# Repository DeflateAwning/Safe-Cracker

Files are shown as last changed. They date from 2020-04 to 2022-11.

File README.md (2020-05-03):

# Safe-Cracker
On a whim, I bought a Sentry Safe on Kijiji for cheap, without the combination. This system uses stepper motors to crack it.

## Acknowledgement
* This project is heavily based off the [sparkfunX project](https://github.com/sparkfunX/Safe_Cracker). Many of the 3D printed components are nearly a direct copy.
	* Licensing Information of the sparkfunX project: https://github.com/sparkfunX/Safe_Cracker/blob/master/LICENSE.md (MIT License)
* A 2040 Extrusion Angle Bracket was used from [Thingiverse.com](https://www.thingiverse.com/thing:3610780), user [jackw01](https://jackw01.github.io).
* A 2040 NEMA17 stepper motor mount was used from [Thingiverse.com](https://www.thingiverse.com/thing:3060289/files), user [grizzly3d](https://www.thingiverse.com/grizzly3d/about)
* Arduino [AccelStepper library](https://www.airspayce.com/mikem/arduino/AccelStepper/index.html).

## Disclaimer
* This project was built to crack open an **empty** safe that was sold to me for cheap, because the owner forgot the combination.
* As per the MIT License, I accept no responsibility for your use/adaptation of this project. Please act morally.

## 3D Printed Components
There are 3 printed components:

### Handle (SafeHandleGrip.stl)
* **Source:** Sparkfun Repository
* **Measured Dimensions:** 38mm x 118.5mm
* Dimensions match the file, using as is for now.

### Handle Pulley (NautilusPulley.stl)
* **Source:** Sparkfun Repository

### Dial (DialGrip.stl)
* **Source:** Personal OpenSCAD Design
* OD of Dial on Safe: \~79mm
* Has 12 notches around the outside
* Designed my own grip for it, supporting M5 bolts

### 2040 Aluminum Extrusion Mounts/Brackets
* Several 90-degree brackets for joining the extrusions together
	* **Source:** Thingiverse.com, see Acknowledgement
* Two motor mounts for mounting the NEMA17 steppers to the extrusions.
	* **Source:** Thingiverse.com, see Acknowledgement

## Electronics
### Devices Used
* The electronics of this system employ the [GRBL CNC Shield v3.00](https://blog.protoneer.co.nz/arduino-cnc-shield/) for the Arduino Uno (note that the associated GRBL firmware is not used). 
* 2x NEMA17 stepper motors, and one SPDT limit switch (used in NO mode)
* A 12v ATX PSU is used for power into the GRBL CNC Shield.
* A 1602 LCD screen may be used, but may not be. To be confirmed if communication will be primarily over Serial or not.
* The system will detect when unlocking was successful by one of two methods (TBD):
	1. ~Use a current sensor on the handle stepper motor (Y Axis). Easier mechnically, more difficult in electronics/firmware.~
	2. Use a limit switch SPDT switch to detect when the handle has moved. More difficult mechanically, easier in electronics/firmware. Far less creative.

### Connections to Arduino
* X Axis -> Dial
	* Dial Step Pin: D2
	* Dial Direction Pin: D5
	* Use 1/8 microstepping
	* Stepper Enable Pin: D8 (for all axes)
* Y Axis -> Handle
	* Handle Step Pin: D3
	* Handle Direction Pin: D6
	* No Microstepping (higher torque)
* X Limit Switch -> Handle Movement Detection
	* Input Pin: D9
	* Internal Pullup Resistor Used
	* Switch used in NO (normally open) mode, connected to GND (internal pullup resistor used)

## Hardware Design
* 2020 and 2040 aluminum extrusions will be used as the main frame, not because they are good, nor because they are cheap, but rather because it is May 2020 and we're all in quarantine, and it's all I have from dismantling an old CNC laser engraver.
* Various 3D printed components will be used. See breakdown of parts in 3D Printed Components section.
* Both stepper motors are **NEMA17** steppers:
	* One is used to turn the dial.
	* The other is used to pull on the handle to test when it is unlocked.

## Firmware Design
* The firmware will be losely based off the firmware provided by the sparkfunX project. It will run on an Arduino Uno, controlling the steppers through the GRBL shield (Arduino pins described in Electronics section).
* Uses the [AccelStepper library](https://www.airspayce.com/mikem/arduino/AccelStepper/index.html) to control the two stepper motors.

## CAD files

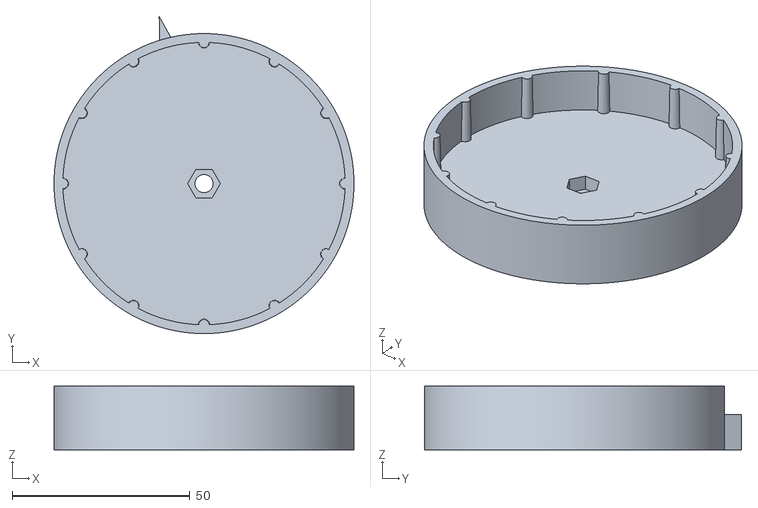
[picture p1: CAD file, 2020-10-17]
3D Models/DialGrip.stl
84.5 x 89.3 x 18.0

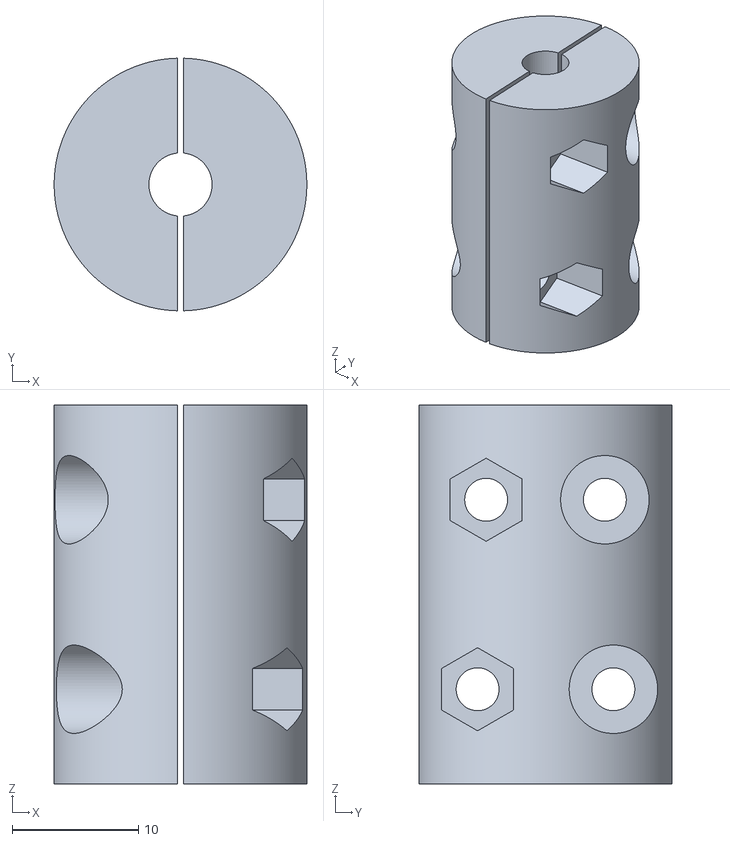
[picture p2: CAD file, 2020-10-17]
3D Models/ShaftCoupler.stl
20.0 x 20.0 x 30.0

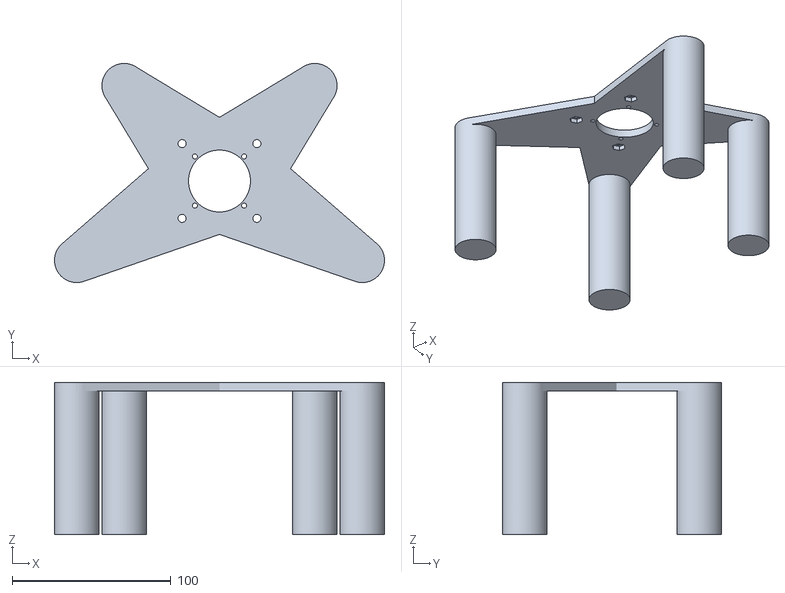
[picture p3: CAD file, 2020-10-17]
3D Models/DialMotorMount.stl
208.0 x 138.1 x 96.0

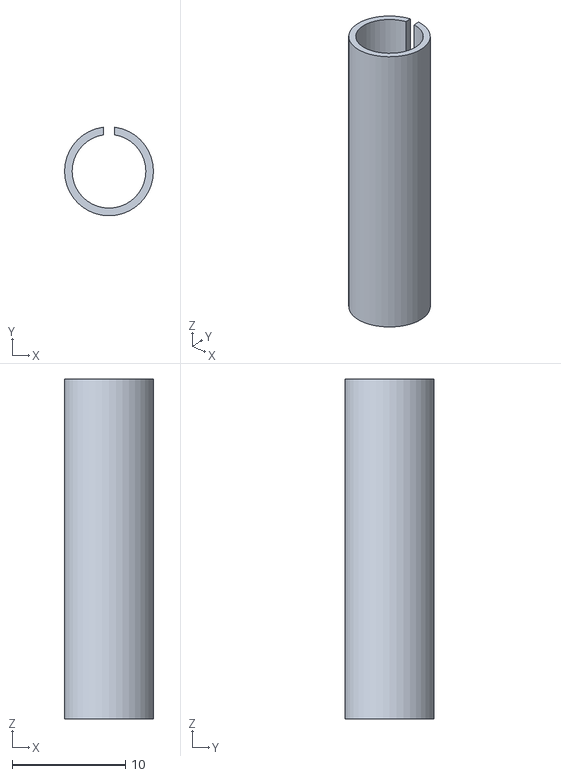
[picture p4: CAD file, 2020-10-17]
3D Models/ShaftBushing.stl
7.85 x 7.81 x 30.0

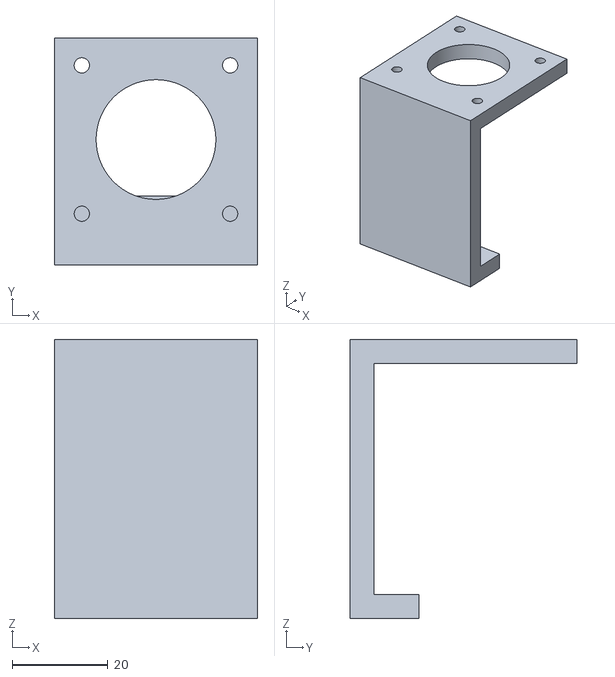
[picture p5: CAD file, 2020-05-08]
3D Models/HandleMotorMount.stl
42.5 x 47.5 x 58.3

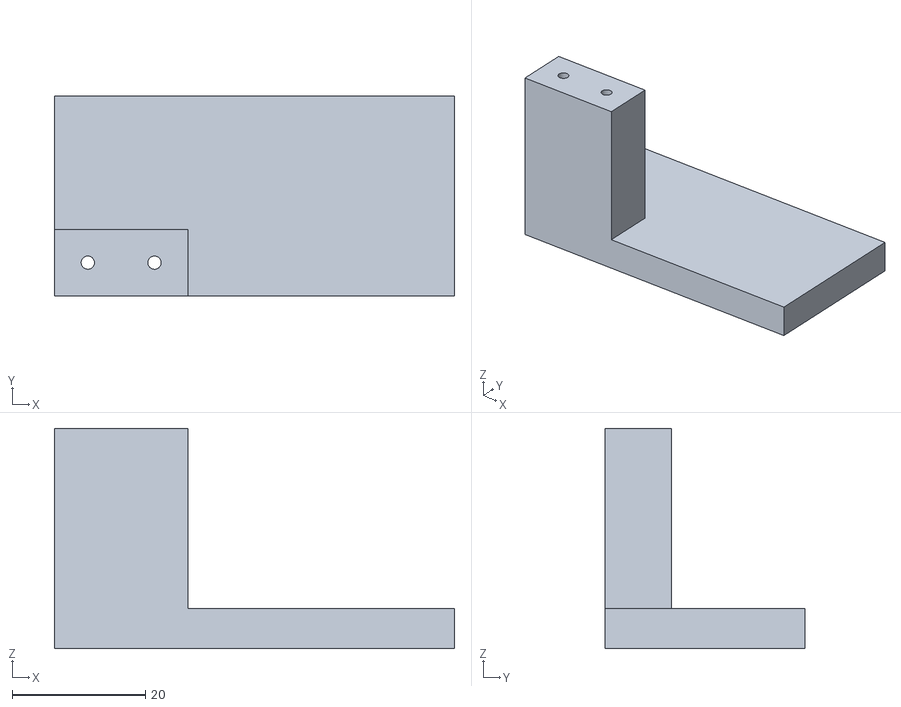
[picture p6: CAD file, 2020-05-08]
3D Models/SwitchMount.stl
60.0 x 30.0 x 33.0

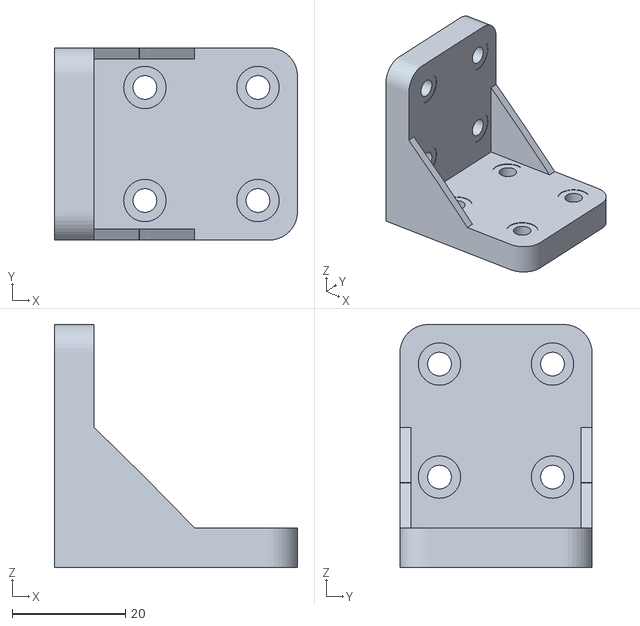
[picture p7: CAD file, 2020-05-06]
3D Models/Parametric_L_Bracket 2040.stl
43.0 x 34.0 x 43.0

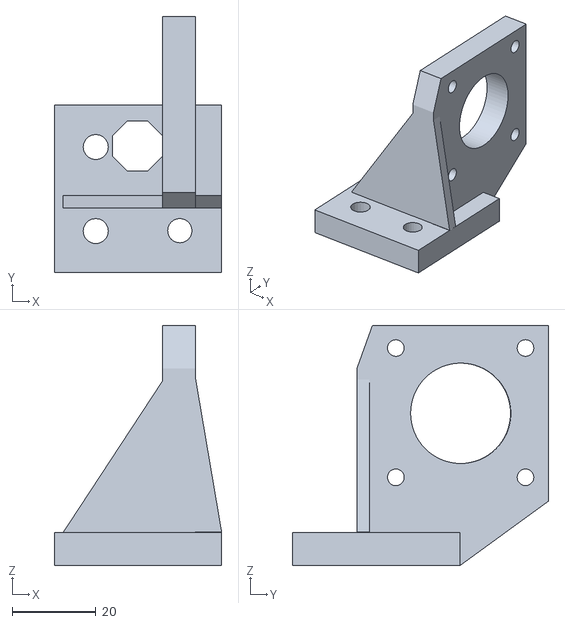
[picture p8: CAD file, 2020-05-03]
3D Models/NEMA17 2040 Mount.stl
40.0 x 61.2 x 57.4

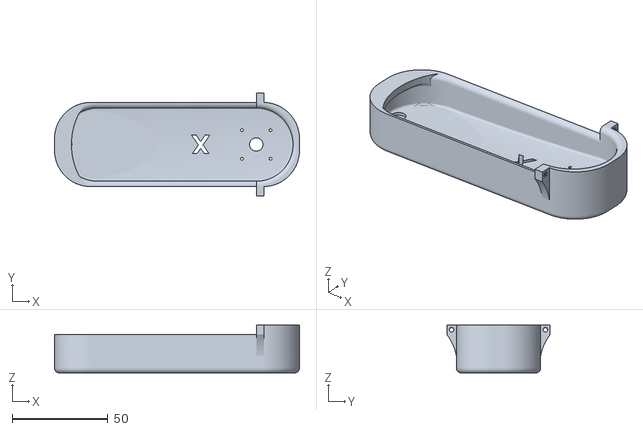
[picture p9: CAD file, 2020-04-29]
3D Models/SafeHandleGrip.stl
128.0 x 53.9 x 25.0

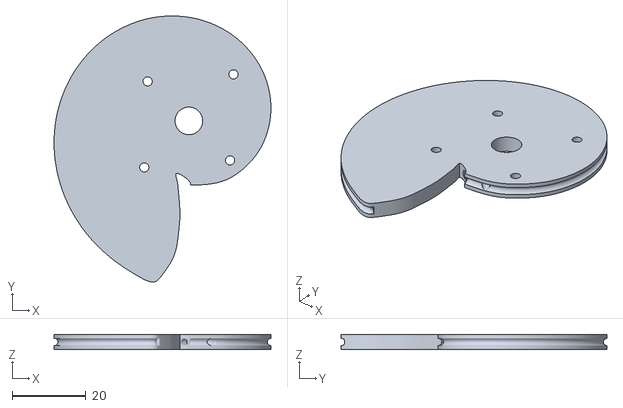
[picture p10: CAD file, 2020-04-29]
3D Models/NautilusPulley.stl
58.9 x 72.2 x 4.00

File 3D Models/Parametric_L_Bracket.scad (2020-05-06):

// Copyright 2019 jackw01. 
// https://jackw01.github.io
// Released under the Creative Commons - Attribution license.

// Screw clearance hole diameter (mm)
screwHoleDiameter = 4.2;
// Screw clearance hole counterbore diameter (mm)
screwHoleCounterboreDiameter = 7.5;
// Screw clearance hole counterbore depth (mm)
screwHoleCounterboreDepth = 0.1;
// Number of screw holes on side 1 (length dimension)
side1Holes = 2;
// Spacing of screw holes on side 1 (mm)
side1HoleSpacing = 20;
// Spacing between corner axis and first screw hole on side 1 (mm)
side1HoleOffset = 16;
// Number of screw holes on side 2 (length dimension)
side2Holes = 2;
// Spacing of screw holes on side 2 (mm)
side2HoleSpacing = 10;
// Spacing between corner axis and first screw hole on side 2 (mm)
side2HoleOffset = 12;
// Number of screw holes in width direction (essentially extends the bracket along the corner axis)
widthHoles = 2; // 1 for 2020, 2 for 2040
// Width of bracket (per hole on width axis) (mm)
widthHoleSpacing = 20;
// Margin around holes on width and length axes (mm)
holeMargin = 7;
// Thickness of the bracket (mm)
thickness = 7;
// Fillet radius (mm)
filletRadius = 5;
// Fillet the corner axis?
filletCornerAxis = 1; // [0:no, 1:yes]
// Fillet radius for corner axis (mm)
filletCornerAxisRadius = 5;
// Gusset on left side?
gussetLeft = 1; // [0:no, 1:yes]
// Gusset on right side?
gussetRight = 1; // [0:no, 1:yes]
// Gusset size (in both dimensions) (mm)
gussetSize = 18;
// Gusset thickness (mm)
gussetThickness = 2;
// Number of segments used to make circular shapes
circleRes = 40;

length = (side1Holes - 1) * side1HoleSpacing + side1HoleOffset + holeMargin;
width = holeMargin * 2 + widthHoleSpacing * (widthHoles - 1);

module hole() {
    union() {
        linear_extrude(height=thickness + length) {
            circle(d=screwHoleDiameter, $fn=circleRes);
        }
        translate([0, 0, thickness - screwHoleCounterboreDepth]) linear_extrude(height=screwHoleCounterboreDepth + length) {
            circle(d=screwHoleCounterboreDiameter, $fn=circleRes);
        }
    }
}

module bracketSide() {
    difference() {
        union() {
            linear_extrude(height=thickness) {
                square([length, width], center=false);
            }
            if (gussetLeft == 1) {
                rotate([-90, 0, 0]) linear_extrude(height=gussetThickness) {
                    polygon(points=[[thickness - 0.2, -thickness + 0.2], [gussetSize + thickness, -thickness + 0.2], [gussetSize / 2 + thickness - 1, -gussetSize / 2 - thickness - 1]]);
                }
            }
            if (gussetRight == 1) {
                translate([0, width - gussetThickness, 0]) rotate([-90, 0, 0]) linear_extrude(height=gussetThickness) {
                    polygon(points=[[thickness - 0.2, -thickness + 0.2], [gussetSize + thickness, -thickness + 0.2], [gussetSize / 2 + thickness - 1, -gussetSize / 2 - thickness - 1]]);
                }
            }
        }
        translate([length - filletRadius, filletRadius, 0]) rotate([0, 0, -90]) linear_extrude(height=length) {
            difference() {
                square([filletRadius * 2, filletRadius * 2], center=false);
                circle(r=filletRadius, $fn=circleRes);
            }
        }
        translate([length - filletRadius, holeMargin * 2 + widthHoleSpacing * (widthHoles - 1) - filletRadius, 0]) linear_extrude(height=length) {
            difference() {
                square([filletRadius * 2, filletRadius * 2], center=false);
                circle(r=filletRadius, $fn=circleRes);
            }
        }
    }
}

module bracketSideHoles() {
    for (x=[0:widthHoles - 1]) {
        for (y=[0:side1Holes - 1]) {
            translate([side1HoleOffset + y * side1HoleSpacing, holeMargin + x * widthHoleSpacing]) hole();
        }
    }
}

difference() {
    union() {
        bracketSide();
        rotate([0, 90, 0]) mirror([1, 0, 0]) bracketSide();
        if (filletCornerAxis == 1) {
            translate([filletCornerAxisRadius * 2, 0, filletCornerAxisRadius * 2]) rotate([0, 90, 90]) linear_extrude(height=width) {
                difference() {
                    square([filletCornerAxisRadius + 0.2, filletCornerAxisRadius + 0.2], center=false);
                    circle(r=filletCornerAxisRadius, $fn=circleRes);
                }
            }
        }
    }
    union() {
        bracketSideHoles();
        rotate([0, 90, 0]) mirror([1, 0, 0]) bracketSideHoles();
    }
}

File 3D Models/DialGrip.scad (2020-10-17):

dialOD = 79+0.5;
dialH = 12;

pointerL = 10;
pointerW = 5;
pointerT = 10;

notchCount = 12;

notchDBig = 3.5;
notchDSmall = 2.8; // v1: 2.5

wallT = 2.5; // thickness of walls
botT = 6; // v1: 3mm, v2: 5.5+1.2, v3: 

holeD = 5.1; // NEMA17 shaft diameter=5mm
nutW = 8.1; // v1: 8 (for M5 bolt), v2: 10, v3: 8.1
nutSink = 4; // v1: boT-1.5mm, v2: botT-1.2, v3: 4 (M5 head thickness)


$fa = 0.5;
$fs = 0.5;

MakeDialGrip();

module MakeDialGrip() {
    difference() {
        union() {
            // Main Grip
            cylinder(d = dialOD + 2*wallT, h=botT + dialH);
            
            // Make dial pointer (doesn't necessarily align with 0 though)
            rotate([0, 0, 180/notchCount])
            translate([0, dialOD/2-1, 0]) linear_extrude(pointerT) polygon([[0, pointerL], [-pointerW/2, 0], [pointerW/2, 0]]);
            
        }
        
        // Remove where the dial goes
        translate([0, 0, botT]) cylinder(d=dialOD, h=100);
        
        // Remove hole through middle
        cylinder(d=holeD, h=100, center=true);
        // Remove nut
        translate([0, 0, botT-nutSink]) cylinder(r=nutW/sqrt(3), h=100, $fn=6);
        
    }
    
    // Add back the grabber notches
    for (rot = [0:360/notchCount:360]) {
        rotate([0, 0, rot]) translate([dialOD/2, 0, 0]) cylinder(d1=notchDBig, d2=notchDSmall, h=botT+dialH);
    }
    
}

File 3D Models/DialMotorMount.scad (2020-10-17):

// Dial Motor Mount for NEMA17 motor onto top of safe, affixed with glue to metal surface


safeThickness = 15; // thickness of edge part
safeDepth = 9.4; // depth of edge part

// Motor Config: NEMA 17 (v1)
//motorW = 38; // width of middle part/hub, for savings (42.5mm is the real width)
motorHoleSpace17 = 31;
motorHoleD17 = 3.2; // screw holes
//motorBigHoleD = 25;


// Motor Config: NEMA 23 (v2)
motorW = 50; // width of middle part/hub, for savings (42.5mm is the real width)
motorHoleSpace23 = 47.14;
motorHoleD23 = 5+0.1; // screw holes
motorBigHoleD = 39;
motorNutW23 = 8;
motorNutT23 = 4.4 - 1.3;



topT = 5.5; // v1: 4; thickness of the pillar-to-arms

baseToMotor = 92+4; // v1: 92; distance from safe top to motor plate

legD = 28;

footD = 35;
footH = 3;
footEnable = false; // enabling makes it not printable oops

// X and Y coords of each leg
legLocs = [[85 * cos(45), 85 * sin(45)], [-85 * cos(45), 85 * sin(45)], // side away from handle
    [90, -50], [-90, -50]];

t = 5;

$fa = 0.75;
$fs = 0.75;

MakeHandleMotorMount();

module MakeHandleMotorMount() {
    difference() {
        union() {
            // Add four cylinder legs
            drawLegs();
            
            // Add top plate
            intersection() {
                for (i = [0,1,2,3]) hull() {
                    // Each leg
                    translate(legLocs[i]) cylinder(d=legD, h=1000, $fn=20);
                    
                    // Middle part for motor
                    cube([motorW, motorW, 400], center=true);
                }
                
                // Keep only part at top plane
                translate([-1000, -1000, baseToMotor-topT]) cube([2000, 2000, topT]);
            }
            
        }
        
        
        
        // Remove motor screw holes (NEMA 17)
        for (x=[1, -1]) for (y=[1, -1]) translate([motorHoleSpace17*x/2, motorHoleSpace17*y/2, 0]) {
            cylinder(d=motorHoleD17, h=1000);
        }
        
        // Remove motor screw holes (NEMA 23)
        for (x=[1, -1]) for (y=[1, -1]) translate([motorHoleSpace23*x/2, motorHoleSpace23*y/2, 0]) {
            cylinder(d=motorHoleD23, h=1000);
            cylinder(r=motorNutW23/sqrt(3), h=baseToMotor-topT+motorNutT23, $fn=6);
        }
        
        // Remove big middle hole
        cylinder(d=motorBigHoleD, h=1000);
        
        
    }
}

module drawLegs() {
    for (i = [0,1,2,3]) {
        translate(legLocs[i]) {
            // draw main leg
            cylinder(d=legD, h=baseToMotor);
            
            // draw foot
            if (footEnable) cylinder(d=footD, h=footH);
        }
    }
}

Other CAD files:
3D Models/HandleMotorMount.scad
3D Models/ShaftBushing.scad
3D Models/ShaftCoupler.scad
3D Models/SwitchMount.scad

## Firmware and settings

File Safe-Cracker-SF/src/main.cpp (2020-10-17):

/*
  Opening a safe using a motor and a servo
  By: Nathan Seidle @ SparkFun Electronics
  Date: February 24th, 2017

  We use a motor with encoder feedback to try to glean the internal workings of the
  safe to reduce the overall solution domain. Then we begin running through
  solution domain, pulling on the handle and measuring it as we go.

  Motor current turning dial, speed = 255, ~350 to 560mA
  Motor current turning dial, speed = 50, = ~60 to 120mA

  TODO:
  servo rest, pull, and open settings to eeprom
  current combination to nvm
*/

#include "main.h"

#include "nvm.h" //EEPROM locations for settings
#include <EEPROM.h> //For storing settings and things to NVM

#include <Servo.h>
Servo handleServo;



//Servo values are found using the testServo() function while the
//cracker was deattached from the safe

//Default settings for 0.8 cubic ft. safe
//On the 1st configuration increasing numbers cause handle to go down
//const byte servoRestingPosition = 15; //Position not pulling/testing on handle
//const byte servoPressurePosition = 50; //Position when doing indent measuring
//const byte servoTryPosition = 80; //Position when testing handle

//Default settings for 1.2 cubic ft. safe
//On the 2nd larger configuration, decreasing numbers cause handle to go down
int servoRestingPosition = 100; //Position not pulling/testing on handle
int servoTryPosition = 50; //Position when testing handle
int servoHighPressurePosition = 40; //Position when doing indent measuring

const int timeServoApply = 350;  //ms for servo to apply pressure. 350 works
const int timeServoRelease = 250;  //Allow servo to release. 250 works
const int timeMotorStop = 125; //ms for motor to stop spinning after stop command. 200 works

int handlePosition; //Used to see how far handle moved when pulled on
//const int handleOpenPosition = 187; //Analog value. Must be less than analog value from servo testing.

//#define CCW 0
//#define CW 1

volatile int steps = 0; //Keeps track of encoder counts. 8400 per revolution so this can get big.
boolean direction = CW; //steps goes up or down based on direction
boolean previousDirection = CW; //Detects when direction changes to add some steps for encoder slack
byte homeOffset = 0; //Found by running findFlag(). Stored in nvm.

//Because we're switching directions we need to add extra steps to take
//up the slack in the encoder
//The greater the adjustment the more negative it goes
int switchDirectionAdjustment = (84 * 0) + 0; //Use 'Test dial control' to determine adjustment size
//84 * 1 - 20 = Says 34 but is actually 33.5 (undershoot)
//84 * 0 = Says 85 but is actually 85.9 (overshoot)

//DiscA goes in CCW fashion during testing, increments 3 each new try.
//We don't know if this is the center of the notch. If you exhaust the combination domain, adjust up or down one.
#define DISCA_START 0

//DiscB goes in CW fashion during testing, increments 3 each new try.
#define DISCB_START (DISCA_START - 3)

//DiscC goes in CCW fashion during testing. 12 indentations, 12 raised bits. Indents are 4.17 numbers wide.
#define DISCC_START 0

//These are the combination numbers we are attempting
int discA = DISCA_START;
int discB = DISCB_START;
int discC = DISCC_START;

//int discA = 30; //Testing only. Don't use.
//int discB = 55;
//int discC = 47;

//Keeps track of the combos we need to try for each disc
//byte maxAAttempts = 33; //Assume solution notch is 3 digits wide
//byte maxBAttempts = 33; //Assume solution notch is 3 digits wide
byte maxCAttempts = 0; //Calculated at startup

//Keeps track of how many combos we've tried on a given disc
//byte discAAttempts = 0;
//byte discBAttempts = 0;
byte discCAttempts = 0;

long startTime; //Used to measure amount of time taken per test

boolean buttonPressed = false; //Keeps track of the 'GO' button.

boolean indentsToTry[12]; //Keeps track of the indents we want to try
int indentLocations[12]; //Encoder click for a given indent
int indentWidths[12]; //Calculated width of a given indent
int indentDepths[12]; //Not really used

void setup()
{
  Serial.begin(115200);
  Serial.println();
  Serial.println();
  Serial.println("Safe Cracker");

  pinMode(motorReset, OUTPUT);
  disableMotor();

  pinMode(encoderA, INPUT);
  pinMode(encoderB, INPUT);

  pinMode(motorPWM, OUTPUT);
  pinMode(motorDIR, OUTPUT);

  pinMode(LED, OUTPUT);

  pinMode(currentSense, INPUT);
  pinMode(servoPositionButton, INPUT_PULLUP);

  pinMode(photo, INPUT_PULLUP);

  pinMode(button, INPUT_PULLUP);

  pinMode(displayClock, OUTPUT);
  pinMode(displayLatch, OUTPUT);
  pinMode(displayData, OUTPUT);

  digitalWrite(displayClock, LOW);
  digitalWrite(displayLatch, LOW);
  digitalWrite(displayData, LOW);

  //Setup the encoder interrupts.
  attachInterrupt(digitalPinToInterrupt(encoderA), countA, CHANGE);
  attachInterrupt(digitalPinToInterrupt(encoderB), countB, CHANGE);

  //Load settings from EEPROM
  homeOffset = EEPROM.read(LOCATION_HOME_OFFSET); //After doing a findFlag calibration, adjust this number up or down until dial is at zero
  Serial.print(F("Home Offset: "));
  Serial.println(homeOffset);

  Serial.println(F("Indent data"));
  for (int indentNumber = 0 ; indentNumber < 12 ; indentNumber++)
  {
    //Load the yes/no for each indent To Try
    indentsToTry[indentNumber] = EEPROM.read(LOCATION_TEST_INDENT_0 + indentNumber); //Boolean
    
    //Get the encoder values for each indent
    EEPROM.get(LOCATION_INDENT_DIAL_0 + (indentNumber * 2), indentLocations[indentNumber]); //Addr, loc. Encoder click for a given indent

    Serial.print(F("IndentNum["));
    Serial.print(indentNumber);
    Serial.print(F("] Encoder["));
    Serial.print(indentLocations[indentNumber]);
    Serial.print(F("] / Dial["));
    Serial.print(convertEncoderToDial(indentLocations[indentNumber]));
    Serial.print(F("] / Width["));
    Serial.print(indentWidths[indentNumber]);
    Serial.print(F("] / Depth["));
    Serial.print(indentDepths[indentNumber]);
    Serial.print(F("] Test["));

    //Print Test if indent will be tested
    if (indentsToTry[indentNumber] == true) Serial.print("Y");
    else Serial.print("N");
    Serial.print(F("]"));

    Serial.println();

  }

  //Get servo settings
  EEPROM.get(LOCATION_SERVO_REST, servoRestingPosition);
  EEPROM.get(LOCATION_SERVO_TEST_PRESSURE, servoTryPosition);
  EEPROM.get(LOCATION_SERVO_HIGH_PRESSURE, servoHighPressurePosition);

  //Validate settings
  if (servoRestingPosition > 250 || servoRestingPosition < 0)
  {
    //New board and/or EEPROM has not been set
    //Assign defaults
    servoRestingPosition = 100;
    servoTryPosition = 50;
    servoHighPressurePosition = 40;

    //Record these defaults to EEPROM
    EEPROM.put(LOCATION_SERVO_REST, servoRestingPosition); //addr, data
    EEPROM.put(LOCATION_SERVO_TEST_PRESSURE, servoTryPosition);
    EEPROM.put(LOCATION_SERVO_HIGH_PRESSURE, servoHighPressurePosition);
  }

  Serial.print(F("servo: resting["));
  Serial.print(servoRestingPosition);
  Serial.print(F("] try["));
  Serial.print(servoTryPosition);
  Serial.print(F("] HighPressure["));
  Serial.print(servoHighPressurePosition);
  Serial.print(F("]"));
  Serial.println();

  //Setup servo
  handleServo.attach(servo);
  handleServo.write(servoRestingPosition); //Goto the resting position (handle horizontal, door closed)
  delay(timeServoRelease * 3); //Allow servo to release, may be in solution slot

  randomSeed(analogRead(A5));

  //Calculate how many indents we need to attempt on discC
  maxCAttempts = 0;
  for (byte x = 0 ; x < 12 ; x++)
    if (indentsToTry[x] == true) maxCAttempts++;

  //At startup discB may be negative. Fix it.
  if (discB < 0) discB += 100;

  //Tell dial to go to zero
  enableMotor(); //Turn on motor controller
  findFlag(); //Find the flag
  //Adjust steps with the real-world offset
  steps = (84 * homeOffset); //84 * the number the dial sits on when 'home'
  setDial(0, false); //Make dial go to zero

  clearDisplay();
  showCombination(0, 0, 0); //Display zeroes
}

void loop()
{
  char incoming;

  //Main serial control menu
  Serial.println();
  Serial.print(F("Combo to start at: "));
  Serial.print(discA);
  Serial.print("/");
  Serial.print(discB);
  Serial.print("/");
  Serial.print(discC);
  Serial.println();

  Serial.println(F("1) Go home and reset dial"));
  Serial.println(F("2) Test dial control"));
  Serial.println(F("3) View indent positions"));
  Serial.println(F("4) Measure indents"));
  Serial.println(F("5) Set indents to test"));
  Serial.println(F("6) Set starting combos"));
  Serial.println(F("7) Calibrate handle servo"));
  Serial.println(F("8) Test handle button"));
  Serial.println(F("9) Test indent centers"));
  Serial.println(F("s) Start cracking"));

  while (!Serial.available())
  {
    if (digitalRead(button) == LOW)
    {
      delay(50);
      if (digitalRead(button) == LOW)
      {
        buttonPressed = true;
        break;
      }
      else
      {
        buttonPressed = false;
      }
    }
    else
    {
      buttonPressed = false;
    }
  }

  if (buttonPressed == true)
  {
    Serial.println(F("Button pressed!"));

    while (digitalRead(button) == false); //Wait for user to stop pressing button
    buttonPressed = false; //Reset variable

    incoming = 's'; //Act as if user pressed start cracking
  }
  else
  {
    incoming = Serial.read();
  }

  if (incoming == '1')
  {
    //Go to starting conditions
    findFlag(); //Detect the flag and center the dial

    Serial.print(F("Home offset is: "));
    Serial.println(homeOffset);

    int zeroLocation = 0;
    while (1) //Loop until we have good input
    {
      Serial.print(F("Enter where dial is actually at: "));

      while (!Serial.available()); //Wait for user input

      Serial.setTimeout(1000); //Must be long enough for user to enter second character
      zeroLocation = Serial.parseInt(); //Read user input

      Serial.print(zeroLocation);
      if (zeroLocation >= 0 && zeroLocation <= 99) break;
      Serial.println(F(" out of bounds"));
    }

    homeOffset = zeroLocation;

    Serial.print(F("\n\rSetting home offset to: "));
    Serial.println(homeOffset);

    EEPROM.write(LOCATION_HOME_OFFSET, homeOffset);

    //Adjust steps with the real-world offset
    steps = (84 * homeOffset); //84 * the number the dial sits on when 'home'

    setDial(0, false); //Turn to zero

    Serial.println(F("Dial should be at: 0"));
  }
  else if (incoming == '2')
  {
    positionTesting(); //Pick random places on dial and prove we can go to them
  }
  else if (incoming == '3')
  {
    //View indent center values
    for (int x = 0 ; x < 12 ; x++)
    {
      Serial.print(x);
      Serial.print(F(": ["));
      Serial.print(lookupIndentValues(x));
      Serial.print(F("]"));
      Serial.println();
    }
  }
  else if (incoming == '4')
  {
    //Measure indents

    int measurements = 0;
    while (1) //Loop until we have good input
    {
      Serial.print(F("How many measurements would you like to take? (Start with 1)"));
      while (!Serial.available()); //Wait for user input
      Serial.setTimeout(1000); //Must be long enough for user to enter second character
      measurements = Serial.parseInt(); //Read user input

      if (measurements >= 1 && measurements <= 20) break;

      Serial.print(measurements);
      Serial.println(F(" out of bounds"));
    }
    Serial.println(measurements);

    measureDiscC(measurements); //Try to measure the idents in disc C. Give function the number of tests to run (get average).
  }
  else if (incoming == '5')
  {
    while (1) //Loop until exit
    {
      int indent = 0;
      while (1) //Loop until we have valid input
      {
        Serial.println("Indents to test:");
        for (int x = 0 ; x < 12 ; x++)
        {
          Serial.print(x);
          Serial.print(": ");

          //Print Test if indent will be tested
          if (indentsToTry[x] == true) Serial.print("Y");
          else Serial.print("N");

          //Print dial value of this indent
          Serial.print(" / ");
          Serial.print(convertEncoderToDial(indentLocations[x]));

          Serial.println();
        }
        Serial.println("Which indent to change?");
        Serial.println("Type 99 to exit");

        while (!Serial.available()); //Wait for user input

        Serial.setTimeout(500); //Must be long enough for user to enter second character
        indent = Serial.parseInt(); //Read user input

        if (indent >= 0 && indent <= 11) break;
        if (indent == 99) break;

        Serial.print(indent);
        Serial.println(F(" out of bounds"));
      }

      if (indent == 99) break; //User wants to exit

      //Flip it
      if (indentsToTry[indent] == true) indentsToTry[indent] = false;
      else indentsToTry[indent] = true;

      //Record current settings to EEPROM
      EEPROM.put(LOCATION_TEST_INDENT_0 + indent, indentsToTry[indent]);
    }

    //Calculate how many indents we need to attempt on discC
    maxCAttempts = 0;
    for (byte x = 0 ; x < 12 ; x++)
      if (indentsToTry[x] == true) maxCAttempts++;
  }
  else if (incoming == '6')
  {
    //Set starting combos
    for (byte x = 0 ; x < 3 ; x++)
    {
      int combo = 0;
      while (1) //Loop until we have good input
      {
        Serial.print(F("Enter Combination "));
        if (x == 0) Serial.print("A");
        else if (x == 1) Serial.print("B");
        else if (x == 2) Serial.print("C");
        Serial.print(F(" to start at: "));
        while (!Serial.available()); //Wait for user input

        Serial.setTimeout(1000); //Must be long enough for user to enter second character
        combo = Serial.parseInt(); //Read user input

        if (combo >= 0 && combo <= 99) break;

        Serial.print(combo);
        Serial.println(F(" out of bounds"));
      }
      Serial.println(combo);
      if (x == 0) discA = combo;
      else if (x == 1) discB = combo;
      else if (x == 2) discC = combo;
    }

  }
  else if (incoming == '7')
  {
    testServo();
  }
  else if (incoming == '8')
  {
    testHandleButton(); //Just pull down on handle and vary distance to hit open button
  }
  else if (incoming == '9')
  {

    setDial(0, false); //Turn to zero without extra spin

    //Test center point of each indent
    for (int indentNumber = 0 ; indentNumber < 12 ; indentNumber++)
    {

      //int dialValue = lookupIndentValues(indentNumber); //Get this indent's dial value
      //setDial(dialValue, false); //Go to the middle of this indent's location

      int encoderValue;
      EEPROM.get(LOCATION_INDENT_DIAL_0 + (indentNumber * 2), encoderValue);

      //84 allows bar to hit indent but just barely
      //* 2 lines the bar with indent nicely
      encoderValue += 84 * 2;

      gotoStep(encoderValue, false); //Goto that encoder value, no extra spin

      Serial.print("dialValue: ");
      Serial.print(convertEncoderToDial(encoderValue));

      Serial.print(" encoderValue: ");
      Serial.println(encoderValue);

      handleServo.write(servoTryPosition); //Apply pressure to handle
      delay(timeServoApply); //Wait for servo to move
      handleServo.write(servoRestingPosition); //Release servo
      delay(timeServoRelease); //Allow servo to release
    }
    Serial.println();

  }
  else if (incoming == 'a')
  {
    handleServo.write(servoRestingPosition);
  }
  else if (incoming == 'z')
  {
    handleServo.write(servoTryPosition);
  }
  else if (incoming == 's') //Start cracking!
  {
    clearDisplay();
    showCombination(discA, discB, discC); //Update display

    startTime = millis();

    //Set the discs to the current combinations (user can set if needed from menu)
    resetDiscsWithCurrentCombo(false); //Do not pause with messages

    while (1)
    {
      nextCombination(); //Try the next combo!

      if (Serial.available())
      {
        byte incoming = Serial.read();
        if (incoming == 'p')
        {
          Serial.println(F("Pausing"));
          while (!Serial.available());
          Serial.read();
          Serial.println(F("Running"));
        }
        else if (incoming == 'x' || incoming == 's')
        {
          Serial.println(F("Cracking stopped"));
          break; //User wants to stop
        }
      }
    } //End eombination loop
  } //End incoming == 's'
}

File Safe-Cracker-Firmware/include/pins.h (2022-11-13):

#ifndef PINS_PROJECT_H
#define PINS_PROJECT_H

// ********** Pin Definitions **********
// Dial -> X Axis on GRBL Board
#define PIN_DIAL_STEP 2
#define PIN_DIAL_DIR  5

// Handle -> Y Axis on GRBL Board
#define PIN_HANDLE_STEP 3
#define PIN_HANDLE_DIR  6

// Handle Open Sensor -> X Axis Limit Switch on GRBL Board
#define PIN_OPEN_SENSOR 9

// Other Pins
#define PIN_STEPPER_ENABLE 8

// Stepper/Driver Configuration
#define stepsPerRev_dial (200*8) // 1/8 microstepping
#define stepsPerRev_handle (200*8) // 1/8 microstepping (use no microstepping for higher torque)
#define maxStepsPerSec_dial (stepsPerRev_dial * 2) // sets the speed for the dial (multiplier is the RPM, basically)

// CW and CCW Direction Constants (feed into dir arguments) -> For Dial Only
#define CW  -1
#define CCW  1


#define NUM_DIGITS 100
const uint16_t stepsPerDigit = stepsPerRev_dial / NUM_DIGITS; // 16 steps per digit


#endif

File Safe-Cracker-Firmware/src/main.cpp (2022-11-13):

#include "main.h"

const int comboIncrement = 2; // number of digits to increase the combination by each time
const float handleTryFractionOfACircle = 1; // fraction of a circle to try to spin the handle motor to unlock

// Construct the Stepper Controllers
AccelStepper dialStepper(AccelStepper::DRIVER, PIN_DIAL_STEP, PIN_DIAL_DIR);
AccelStepper handleStepper(AccelStepper::DRIVER, PIN_HANDLE_STEP, PIN_HANDLE_DIR);

int currentPosDigit = 0;


void setup() {
	// Begin serial communication
	Serial.begin(115200);
	Serial.println("***** Safe-Cracker Starting *****");

	// Set the stepper config, pinmodes
	setupSteppers();

	// Test functionality of each system component/control function
	doHardwareTest();

	// Instruct the user to set the safe to a known state
	doSetupInstructions();

	// Do the cracking
	doCracking();
}

/**
Setup the stepper motor configuration and pin modes. These values may need tuning.
*/
void setupSteppers() {
	// Set Pin Modes
	pinMode(PIN_DIAL_STEP, OUTPUT);
	pinMode(PIN_DIAL_DIR, OUTPUT);
	pinMode(PIN_HANDLE_STEP, OUTPUT);
	pinMode(PIN_HANDLE_DIR, OUTPUT);
	pinMode(PIN_STEPPER_ENABLE, OUTPUT);
	pinMode(PIN_OPEN_SENSOR, INPUT_PULLUP);

	// Set stepper settings
	dialStepper.setMaxSpeed(maxStepsPerSec_dial); // in steps/second, set to 3 rev/second
	dialStepper.setAcceleration(maxStepsPerSec_dial*4);
	dialStepper.setSpeed(dialStepper.maxSpeed() - 1);

	handleStepper.setMaxSpeed(stepsPerRev_handle * 1);
	handleStepper.setAcceleration(stepsPerRev_handle * 4);
	handleStepper.setSpeed(handleStepper.maxSpeed() - 1);
}


void doHardwareTest() {
	bool enableTest_spinFullCircles        = true;
	bool enableTest_spinToDigit            = false;
	bool enableTest_printInputSwitch       = true;
	bool enableTest_testHandle             = true;

	Serial.println("Hardware test beginning.");

	// Test that motor enable works, motors receiving power
	Serial.println("Motors being disabled (3s) then enabled (2s). Ensure they lock.");
	setStepperEnable(false);
	delay(3000);
	setStepperEnable(true);
	delay(2000);
	Serial.println();

	
	// Test that the dial driver works
	if (enableTest_spinFullCircles) {
		Serial.println("The dial will spin a full circle clockwise, wait a second, then spin back CCW.");
		for (int i = 0; i < 1; i++) { // change to i < 2 to do twice
			//dialStepper.runToNewPosition(stepsPerRev_dial * 2); // original, use absolute position
			dialStepper.move(CW * stepsPerRev_dial);
			runStepperUntilDone(dialStepper);

			Serial.println("\t2 circles CW done.");
			delay(1000);
			
			//dialStepper.runToNewPosition(0); // original, use absolute position
			dialStepper.move(CCW * stepsPerRev_dial);
			runStepperUntilDone(dialStepper);

			Serial.println("\tSpin back CCW done.");
			delay(1000);
			Serial.println();
		}
	}


	// Test that the dial spinToDigit function works
	if (enableTest_spinToDigit) {
		Serial.println("Spinning to each digit, CW in 10s.");
		for (int digit = 10; digit < 50; digit += 10) {
			Serial.print("Spin to "); Serial.print(digit); Serial.print(" CCW (short way) ...");
			spinToDigit(0, digit, CCW);
			Serial.println("Done.");

			delay(5000);
		}

		// spin back to 0
		spinToDigit(0, 0, CCW);
		delay(5000);

		Serial.println("Spinning to each digit, CW in 10s.");
		for (int digit = 10; digit < 50; digit += 10) {
			Serial.print("Spin to "); Serial.print(digit); Serial.println(" CW (long way) ...");
			spinToDigit(0, digit, CW);
			Serial.println("Done.");

			delay(5000);
		}
	}
	
	


	// Test that the input switch works
	if (enableTest_printInputSwitch) {
		Serial.println("The input switch will be tested 10 times in 10 seconds. Try triggering it and seeing results.");
		for (int i = 0; i < 10; i++) {
			if (readSafeOpen()) {
				Serial.print("Safe Unlocked | ");
			}
			else {
				Serial.print("Safe Locked | ");
			}
			delay(1000);
		}
		Serial.println("\n");
	}

	// Test that the safe opening mechanism (handle) works
	if (enableTest_testHandle) {
		Serial.println("The handle opener will now be tested 3 times.");
		Serial.println("Let it fail once, then pretend it opened and trigger the switch once.");
		for (int i = 0; i < 3; i++) {
			long startTime = millis();
			if (checkSafeOpenHandle()) {
				Serial.println("\tSafe handle open. Safe unlocked.");
			}
			else {
				Serial.println("\tSafe handle not opened. Safe still locked.");
			}
			Serial.print("\tHandle Open Attempt took "); Serial.print(millis()-startTime); Serial.println("ms, waiting 3s now.");
			delay(3000);
		}
		Serial.println();
	}


}

/**
 * Instructs the user to set the dial stepper to a known state, and to set the handle tension. Waits for the switch to trigger to begin.
 */
void doSetupInstructions() {
	// disable steppers
	setStepperEnable(false);

	Serial.println("The steppers are now disabled. Turn the dial to face to zero, and ensure the handle trigger is setup. Then, press the switch.");
	while (! readSafeOpen()) {} // wait until button is pressed
	Serial.println("Safe dial position is now set to 0.");
	delay(2000); // debounce the button, in case they're holding it

	// enable steppers
	setStepperEnable(true);
}

/**
 * Does the cracking.
 */
void doCracking() {
	// enable steppers
	setStepperEnable(true);

	for (int digit1 = 0; digit1 < NUM_DIGITS; digit1 += comboIncrement)
		for (int digit2 = 0; digit2 < NUM_DIGITS; digit2 += comboIncrement)
			for (int digit3 = 0; digit3 < NUM_DIGITS; digit3 += comboIncrement) {
				Serial.print("Trying combination: "); Serial.print(digit1); Serial.print("-"); Serial.print(digit2); Serial.print("-"); Serial.print(digit3);
				Serial.print(" ... ");

				// Actually try the digits
				spinToDigit(4, digit1, CCW, false);
				spinToDigit(3, digit2, CW, false);
				spinToDigit(2, digit3, CCW, false);

				if (checkSafeOpenHandle()) {
					Serial.println("Handle opened!!");
					Serial.println("You're excited, so write down the number the safe is currently on.");
					Serial.print("The software thinks the safe is currently on: "); Serial.print(currentPosDigit);
					Serial.println();

					// Pause forever
					while (1) {
						delay(1000);
					}
				}
				else {
					// Handle didn't open this time
					Serial.println("Shit, not again.");
				}
			}
}
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

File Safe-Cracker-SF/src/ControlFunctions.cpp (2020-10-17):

/*
  These are the general control functions

  setDial - go to a given dial position (0 to 99)
  resetDial - spin the dial twice to move reset discs A, B, and C. Stop at 0.
  findFlag - tell dial to return to where the flag interruts the photogate. Depending on how the robot is attached to dial, this may be true zero or an offset
  setDiscsToStart - Go home, clear dial, go to starting numbers

  Supporting functions:
  gotoStep - go to a certain step value out of 8400. The DC motor has momentum so this function, as best as possible, goes to a step value
  stepRequired - calcs the steps of the encoder to get from current position to a given position
  convertDialToEncoder - given a dial number, how many encoder steps is that?
  convertEncoderToDial - given encoder value, what is the dial position?
  enable/disableMotor - controls the enable pin on motor driver
  turnCW/CCW - controls the direction pin on motor driver

*/

#include "main.h"


//Given a step value, go to that step
//Assume user has set direction prior to calling
//Returns the delta from what you asked and where it ended up
//Adding a full rotation will add a 360 degree full rotation
int gotoStep(int stepGoal, boolean addAFullRotation)
{
  //Coarse speed and window control how fast we arrive at the digit on the dial
  //Having too small of a window or too fast of an attack will make the dial
  //overshoot.
  int coarseSpeed = 200; //Speed at which we get to coarse window (0-255). 150, 200 works. 210, 230 fails
  int coarseWindow = 1250; //Once we are within this amount, switch to fine adjustment
  int fineSpeed = 50; //Less than 50 may not have enough torque
  int fineWindow = 32; //One we are within this amount, stop searching

  //Because we're switching directions we need to add extra steps to take
  //up the slack in the encoder
  if (direction == CW && previousDirection == CCW)
  {
    steps += switchDirectionAdjustment;
    if (steps > 8400) steps -= 8400;
    previousDirection = CW;
  }
  else if (direction == CCW && previousDirection == CW)
  {
    steps -= switchDirectionAdjustment;
    if (steps < 0) steps += 8400;
    previousDirection = CCW;
  }

  setMotorSpeed(coarseSpeed); //Go!
  while (stepsRequired(steps, stepGoal) > coarseWindow) ; //Spin until coarse window is closed

  //After we have gotten close to the first coarse window, proceed past the goal, then proceed to the goal
  if (addAFullRotation == true)
  {
    int tempStepGoal = steps + 8400/2; //Move 50 away from current position
    if (tempStepGoal > 8400) tempStepGoal -= 8400;
    
    //Go to temp position
    while (stepsRequired(steps, tempStepGoal) > coarseWindow) ; 
        
    //Go to stepGoal
    while (stepsRequired(steps, stepGoal) > coarseWindow) ; //Spin until coarse window is closed
  }

  setMotorSpeed(fineSpeed); //Slowly approach

  while (stepsRequired(steps, stepGoal) > fineWindow) ; //Spin until fine window is closed

  setMotorSpeed(0); //Stop

  delay(timeMotorStop); //Wait for motor to stop

  int delta = steps - stepGoal;

  /*if (direction == CW) Serial.print("CW ");
    else Serial.print("CCW ");
    Serial.print("stepGoal: ");
    Serial.print(stepGoal);
    Serial.print(" / Final steps: ");
    Serial.print(steps);
    Serial.print(" / delta: ");
    Serial.print(delta);
    Serial.println();*/

  return (delta);
}

//Calculate number of steps to get to our goal
//Based on current position, goal, and direction
//Corrects for 8400 roll over
int stepsRequired(int currentSteps, int goal)
{
  if (direction == CW)
  {
    if (currentSteps >= goal) return (currentSteps - goal);
    else if (currentSteps < goal) return (8400 - goal + currentSteps);
  }
  else if (direction == CCW)
  {
    if (currentSteps >= goal) return (8400 - currentSteps + goal);
    else if (currentSteps < goal) return (goal - currentSteps);
  }

  Serial.println(F("stepRequired failed")); //We shouldn't get this far
  Serial.print(F("Goal: "));
  Serial.println(goal);
  Serial.print(F("currentSteps: "));
  Serial.println(currentSteps);

  return (0);
}

//Given a dial number, goto that value
//Assume user has set the direction before calling
//Returns the dial value we actually ended on
int setDial(int dialValue, boolean extraSpin)
{
  //Serial.print("Want dialValue: ");
  //Serial.println(dialValue);

  int encoderValue = convertDialToEncoder(dialValue); //Get encoder value
  //Serial.print("Want encoderValue: ");
  //Serial.println(encoderValue);

  gotoStep(encoderValue, extraSpin); //Goto that encoder value
  //Serial.print("After movement, steps: ");
  //Serial.println(steps);

  int actualDialValue = convertEncoderToDial(steps); //Convert back to dial values
  //Serial.print("After movement, dialvalue: ");
  //Serial.println(actualDialValue);

  return (actualDialValue);
}

//Spin until we detect the photo gate trigger
void findFlag()
{
  byte fastSearch = 255; //Speed at which we locate photogate
  byte slowSearch = 50;

  turnCW();

  //If the photogate is already detected spin until we are out
  if (flagDetected() == true)
  {
    Serial.println(F("We're too close to the photogate"));
    int currentDial = convertEncoderToDial(steps);
    currentDial += 50;
    if (currentDial > 100) currentDial -= 100;
    setDial(currentDial, false); //Advance to 50 dial ticks away from here
  }

  //Begin spinning
  setMotorSpeed(fastSearch);

  while (flagDetected() == false) delayMicroseconds(1); //Spin freely

  //Ok, we just zipped past the gate. Stop and spin slowly backward
  setMotorSpeed(0);
  delay(timeMotorStop); //Wait for motor to stop spinning
  turnCCW();

  setMotorSpeed(slowSearch);
  while (flagDetected() == false) delayMicroseconds(1); //Find flag

  setMotorSpeed(0);
  delay(timeMotorStop); //Wait for motor to stop

  //Adjust steps with the real-world offset
  steps = (84 * homeOffset); //84 * the number the dial sits on when 'home'

  previousDirection = CCW; //Last adjustment to dial was in CCW direction
}

//Set the discs to the current combinations (user selectable)
void resetDiscsWithCurrentCombo(boolean pause)
{
  resetDial(); //Clear out everything

  //Set discs to this combo
  turnCCW();
  int discAIsAt = setDial(discA, false);
  Serial.print("DiscA is at: ");
  Serial.println(discAIsAt);
  if (pause == true) messagePause("Verify disc position");

  turnCW();
  //Turn past disc B one extra spin
  int discBIsAt = setDial(discB, true);
  Serial.print("DiscB is at: ");
  Serial.println(discBIsAt);
  if (pause == true) messagePause("Verify disc position");

  turnCCW();
  int discCIsAt = setDial(discC, false);
  Serial.print("DiscC is at: ");
  Serial.println(discCIsAt);
  if (pause == true) messagePause("Verify disc position");
  

  discCAttempts = -1; //Reset
}
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

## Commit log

2020-04-29 Add 3D files
    [DialGrip.scad, DialGrip.stl, NautilusPulley.stl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]
2020-05-03 Add 2040 Bracket and NEMA17 mount models
    [NEMA17 2040 Mount.stl, Parametric_L_Bracket.scad, Parametric_L_Bracket.stl]
2020-05-06 Update dial by making thicker bottom, update 2040 bracket to be right size
    [DialGrip.scad, DialGrip.stl, Parametric_L_Bracket 2040.stl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]
2020-05-06 Fix firmware self-test after testing on Arduino
    [Safe-Cracker-Firmware.ino]
2020-05-06 Fix screw hole dimensions on 2040 L Bracket
    [Parametric_L_Bracket 2040.stl, Parametric_L_Bracket.scad]
2020-05-07 Add first revision of switch mount
    [SwitchMount.scad, SwitchMount.stl]
2020-05-08 Disable bump on SwitchMount
    [SwitchMount.scad, SwitchMount.stl]
2020-05-08 Add mount for motor that opens the handle
    [HandleMotorMount.scad, HandleMotorMount.stl]
2020-07-29 Make Dial Motor Mount, minor firmware test upgrades
    [DialMotorMount.scad, DialMotorMount.stl]
2020-10-17 Add models for 3D printed parts for NEMA34 motor
    [DialGrip.scad, DialGrip.stl, DialMotorMount.scad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]
